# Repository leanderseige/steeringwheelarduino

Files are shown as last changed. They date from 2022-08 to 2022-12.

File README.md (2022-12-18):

# Steering Wheel Arduino

I have been asked for a PC steering wheel and I decided to not just buy one but to build our own steering wheel ourselves.

Following some excellent sources on the internet it was not too hard to build our own simple steering wheel. The most important sources were [@eglix](https://github.com/eglix)s videos on YT https://www.youtube.com/watch?v=OD7MRSHHSPQ and https://youtu.be/cj_OGSozPsY as well as his 3D models of gears and the holder: https://github.com/eglix/Projeler/tree/master/DIY_SIM_Wheel

What we added on our own:
* a button for quick in-game calibration
* we wrote our own software
* invented some kind of rubber band centering
* used another steering wheel (five screws instead of six)

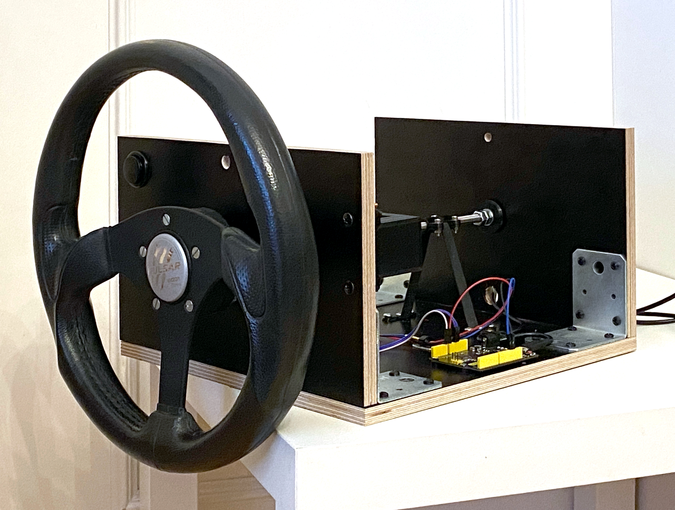
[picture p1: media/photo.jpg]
wheel photo 1


# How does it perform?

Check out this very short video:

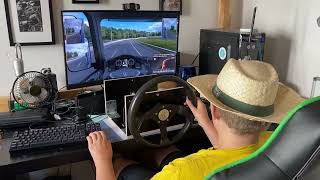
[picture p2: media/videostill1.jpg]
Watch the video (https://youtu.be/0jyAVrumM1k)


# Software

As I saw how easy it is to program an Arduino Leonardo I chose to not use the existing binary tools flying around on the internet but to write my own software. One needs just a couple of lines to get everything working.

Just set up the Arduino IDE and install the following two libraries:
* ArduinoJoystickLibrary (I installed it from the latest ZIP, https://github.com/MHeironimus/ArduinoJoystickLibrary/wiki)
* optional: TM1637 Driver (I installed it from within the IDE's library management, https://github.com/AKJ7/TM1637)

There are three source code files in src/
* minimal.ino - the very minimal version, just sets the Z-Axis Rotation
* minimal-button.ino - I added a button to calibrate the middle position of the wheel (this one is in production)
* minimal-button-led.ino - for full fancyness one can add two TM1637 compatible displays to see the values at any time

Windows recognizes the wheel while programming just right away.

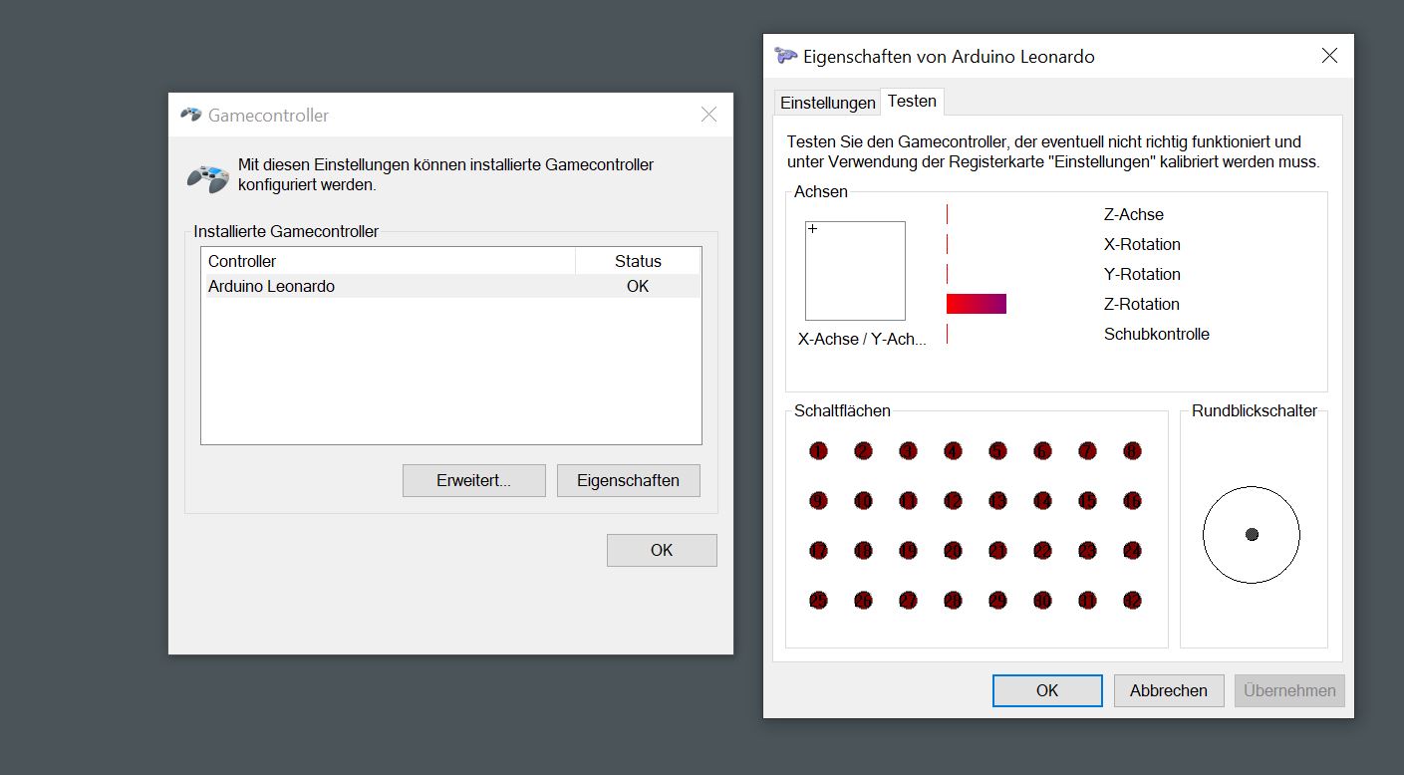
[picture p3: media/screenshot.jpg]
Screenshot Windows


# Hardware

Click on the photo for a short video!

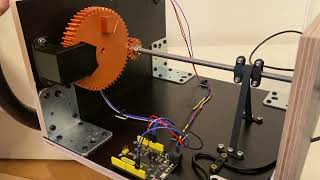
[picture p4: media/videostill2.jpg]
Inside Video (https://youtu.be/oHTkMrLjo54)


The gears and the holder are from [@eglix](https://github.com/eglix)s repo: https://github.com/eglix/Projeler/tree/master/DIY_SIM_Wheel

Our first holder broke. Therefore we recommend a rather high level of infill. We also increased the thickness of the walls so that the small parts become completely solid.

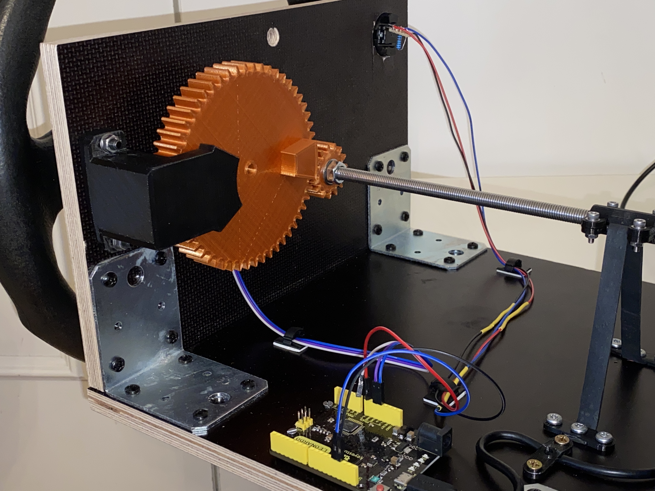
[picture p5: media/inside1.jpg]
Photo Inside


## Steering wheel

We got our wheel from a local car recycling yard. First we got a Volvo wheel including an airbag but people told us that it would be a bad idea to disassemble the airbag ourselves. I followed this advice and traded that wheel for another one without an airbag. We were lucky and found this nice Pulsar Victor sports steering wheel for just €30.

This wheel is mounted using five M5 screws. I designed a separate adapter for it to mount it to the 8mm threaded rod. The file is called 5ScrewWheelTo8mm.stl

## Ball bearings

We recycled some old bearings from a skateboard. Inserted two ball bearings including spacers on each side of each wall.

## Other things

Threaded 8mm rod, washers and nuts as well as coated plywood came from a local hardware store.

## Rubber band

In order the pull the wheel back towards the center I invented a simple mechanism using a rubber band. The file for 3D-printing is called Rubber_Band_Mounts.stl I already had rubber band at hand from an earlier project. But here is the source anyway: https://amzn.to/3j2F91a

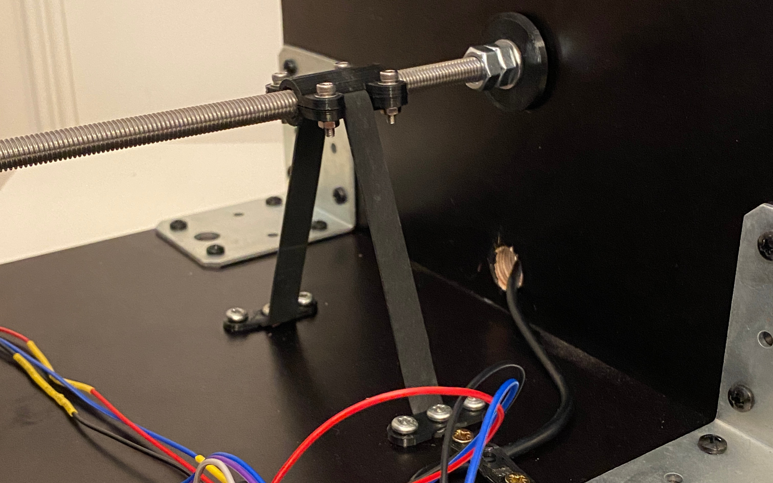
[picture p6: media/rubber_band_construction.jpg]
Rubber Band Construction


## Electronics

Wiring is very easy. However, I do not guarantee the correctness of anything. Reproduce the circuit or use the software code on your own risk.

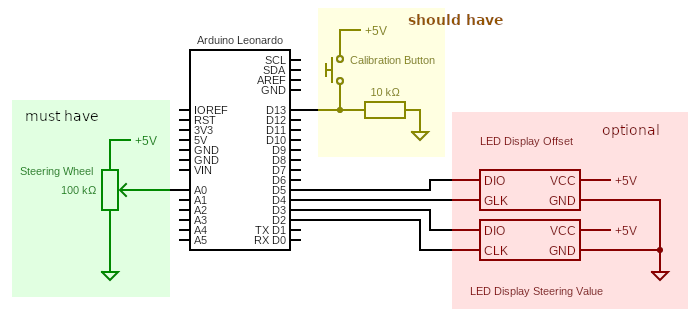
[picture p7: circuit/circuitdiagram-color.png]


* I used an Arduino Leonardo clone from https://amzn.to/3YuZrAF - First I accidentely wired the potentiometer the wrong way and caused a short circuit on the power line. The voltage regulator on the Leonardo started to smell burned and functionality broke down. However, after fixing the wrong wiring the Leonardo went back to normal operation. We decided to not swap the Leonardo for a fresh one. If it survived this harsh start it would live for a long time with us, so we hope.

* Resistor and potentiometer (B100K) were already available.

* Arcade button: https://amzn.to/3hwFdGj

* Optional LED display, TM1637 compatible: https://amzn.to/3W9B1er

We did not include the LED displays in the final product but here is how it looked like:

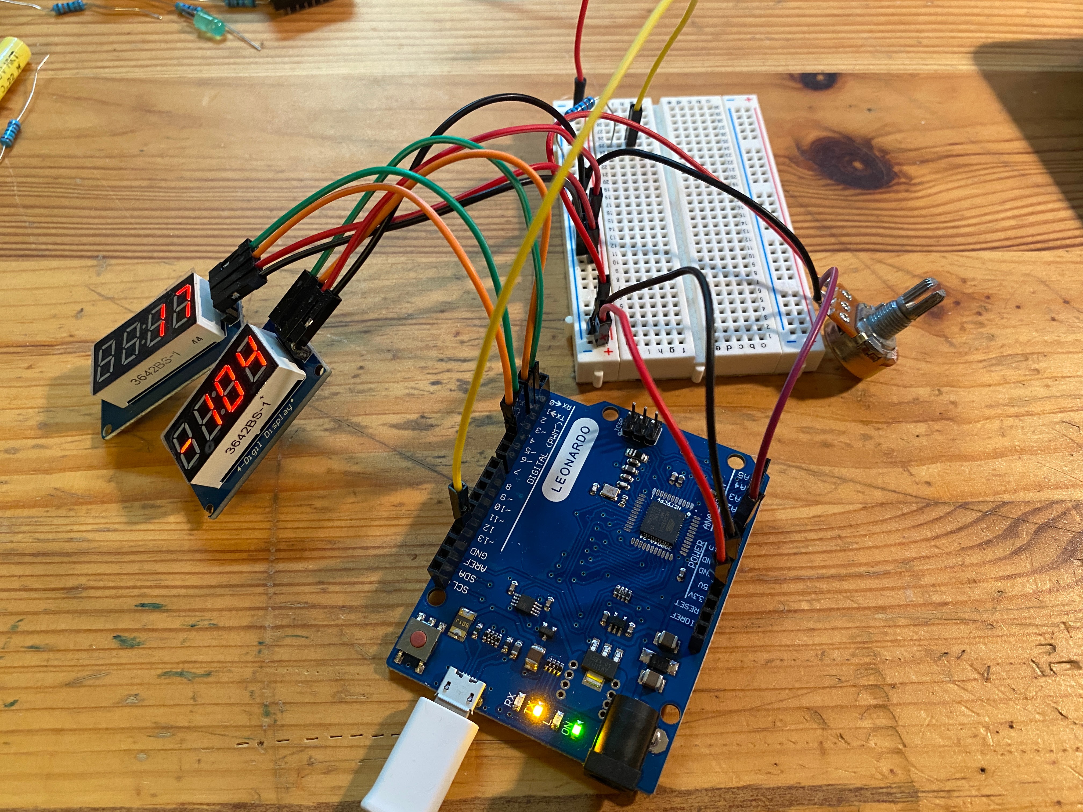
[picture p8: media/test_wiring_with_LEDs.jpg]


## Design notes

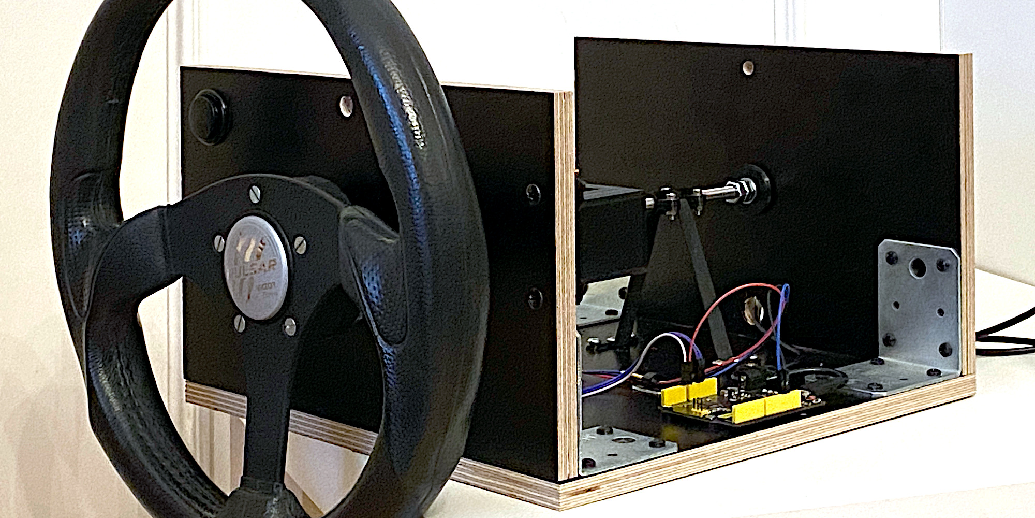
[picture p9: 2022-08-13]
media/socialmedia.jpg

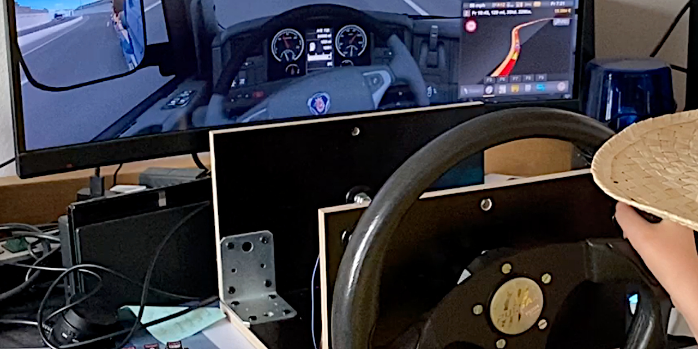
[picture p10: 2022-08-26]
media/socialmedia2.jpg

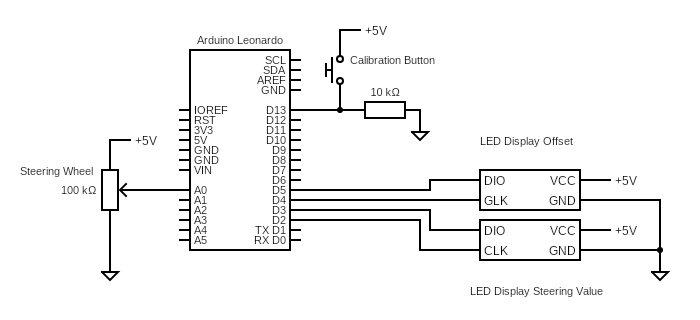
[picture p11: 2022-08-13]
circuit/circuitdiagram.png

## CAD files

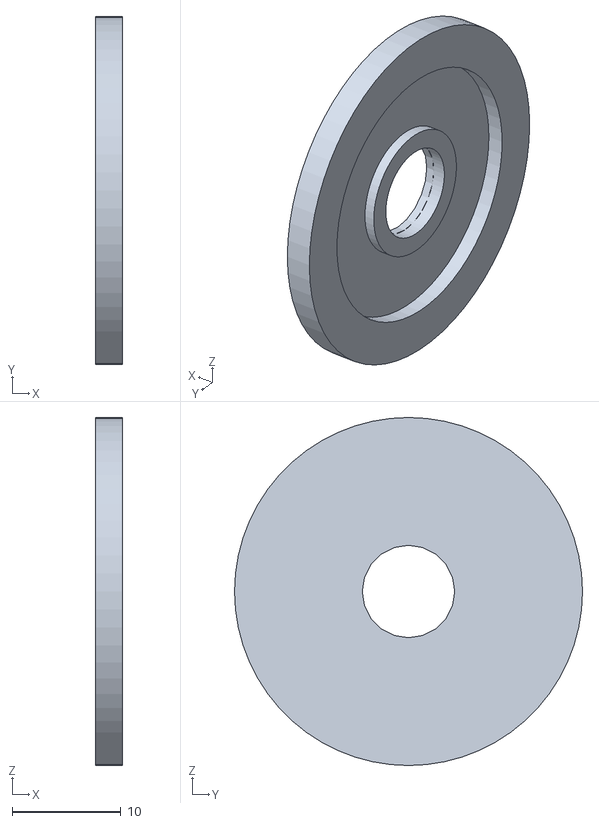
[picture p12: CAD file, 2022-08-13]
stl/Spacer_Ball_Bearings.stl
2.50 x 32.0 x 32.0

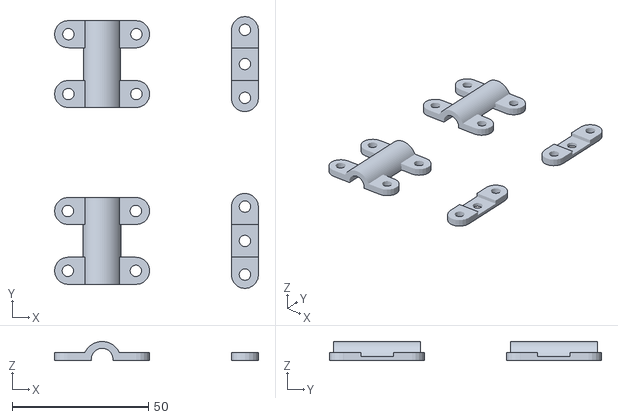
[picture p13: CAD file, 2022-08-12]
stl/Rubber_Band_Mounts.stl
75.0 x 100.0 x 7.00

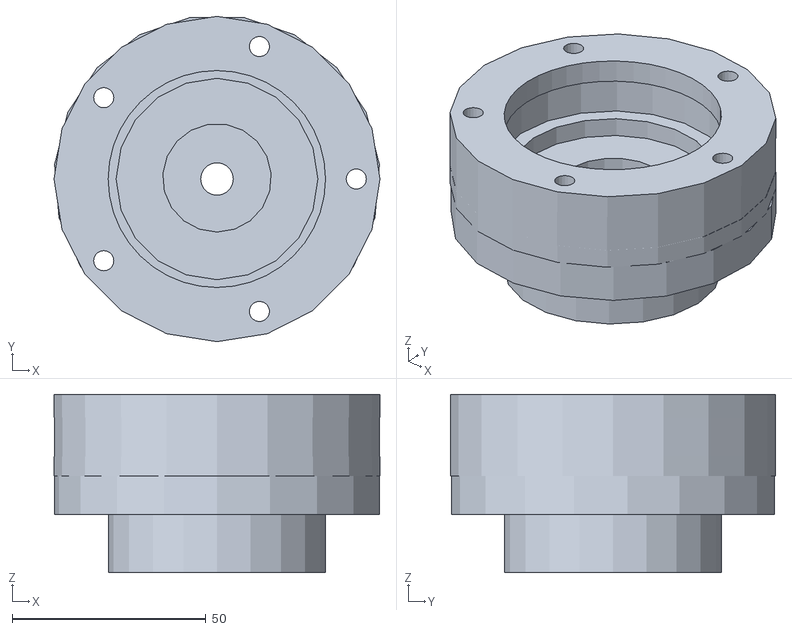
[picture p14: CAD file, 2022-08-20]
stl/5ScrewWheelTo8mm.stl
84.2 x 84.0 x 46.0

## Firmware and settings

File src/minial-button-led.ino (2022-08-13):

/*
 * Steering Wheel Software
 * Version: Minimal +Button +LED-Display
 *
 * (c) Leander Seige, 2022, GPL V3
 */

#include "Joystick.h"
#include <TM1637.h> // by AKJ, https://github.com/AKJ7/TM1637

Joystick_ Joystick;

int off = 0;
TM1637 tmA(2, 3);
TM1637 tmB(4, 5);
char d[6];

void setup() {
  Serial.begin(9600);

  Joystick.setRxAxisRange(0, 1023);
  Joystick.setRyAxisRange(0, 1023);
  Joystick.setRzAxisRange(-512, 512);
  Joystick.begin();

  pinMode(13, INPUT);

  tmA.begin();
  tmB.begin();
}

void loop() {
  int b = digitalRead(13);
  int z = analogRead(A0)-512;
  if(b==1) {
    off = z;
  }
  z = z - off;
  Joystick.setRxAxis(0);
  Joystick.setRyAxis(0);
  Joystick.setRzAxis(z);
  sprintf(d,"%4d",z);
  tmA.display(String(d));
  sprintf(d,"%4d",off);
  tmB.display(String(d));
  Serial.println(String(z)+" "+String(b)+" "+String(off));
}

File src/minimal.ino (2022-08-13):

/*
 * Steering Wheel Software
 * Version: Minimal
 *
 * (c) Leander Seige, 2022, GPL V3
 */

#include "Joystick.h"

Joystick_ Joystick;

void setup() {
  Serial.begin(9600);

  Joystick.setRxAxisRange(0, 1023);
  Joystick.setRyAxisRange(0, 1023);
  Joystick.setRzAxisRange(-512, 512);
  Joystick.begin();
}

void loop() {
  int z = analogRead(A0)-512;
  Joystick.setRxAxis(0);
  Joystick.setRyAxis(0);
  Joystick.setRzAxis(z);
  Serial.println(z);
}

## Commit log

2022-08-13 folder created
    [Rubber_Band_Mounts.stl, Spacer_Ball_Bearings.stl]
2022-08-13 circuit moved
2022-08-13 upd circuit
2022-08-20 this and that
    [5ScrewWheelTo8mm.stl, Rubber_Band_Mounts.stl, Spacer_Ball_Bearings.stl]
